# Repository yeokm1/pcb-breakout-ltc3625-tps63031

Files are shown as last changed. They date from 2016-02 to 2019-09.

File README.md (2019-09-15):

# pcb-breakout-ltc3625-tps63031
Pin breakout of the LTC3625 supercapacitor charger with TPS63031 3.3V regulator to through-hole pin headers for prototyping

<b>WARNING</b>: Consult the LTC3625 and TPS63031 datasheets in conjunction with the Eagle schematic to learn proper usage of this breakout.

If your project uses low currents it might be better enable power-save mode by setting the power save (PS) pin 7 of the TPS63031 to ground.

## PCB Design software and addons used

1. Eagle 7.5.0: I use Standard but Light should still be able to open/modify the files.
2. My custom ltc3625 library
3. [Seed-OPL-Connector](http://www.seeedstudio.com/wiki/File:OPL_eagle_library.zip)
4. [Coilcraft inductor](https://github.com/robertstarr/lbr_user/blob/master/inductor-coilcraft.lbr)
5. [TPS63031](http://e2e.ti.com/support/development_tools/webench_design_center/f/234/p/379556/1338022)

## Images
None at this time

##Schematic drawings
Images are exported from Eagle at 600dpi.

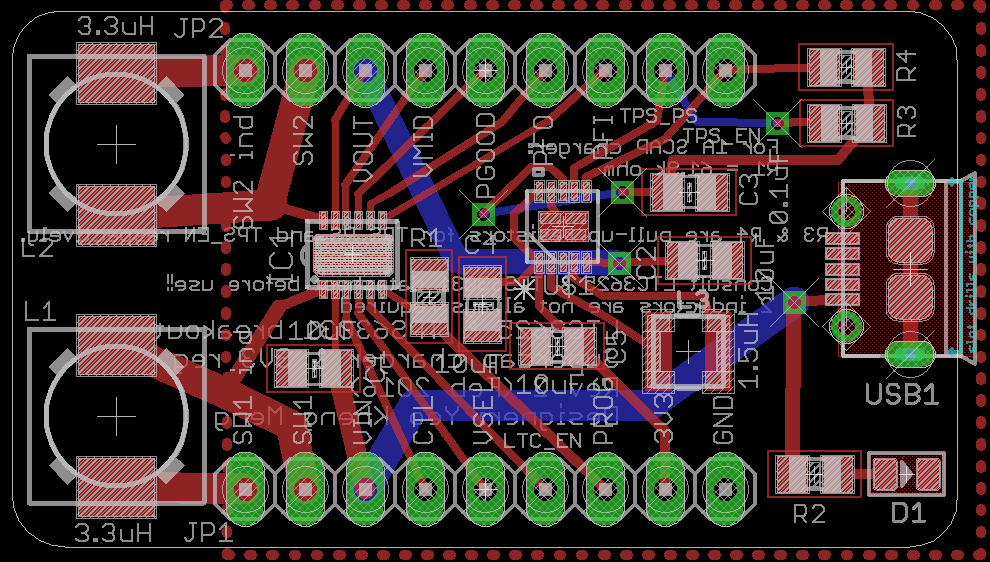
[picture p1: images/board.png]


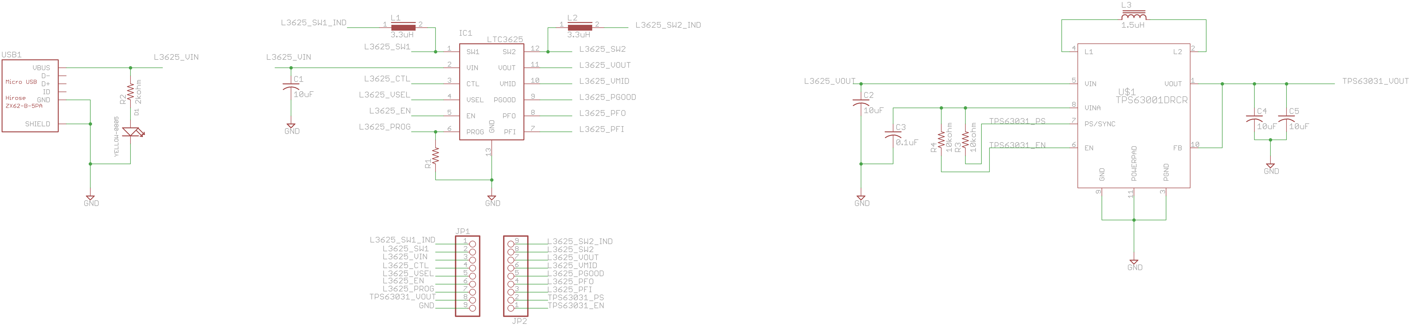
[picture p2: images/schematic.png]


## Parts required
1. Linear Technology LTC3625
2. Texas Instruments TPS63031
3. 4x 10uF 0805 ceramic capacitors
4. 0.1uF 0805 ceramic capacitor
5. 2x 3.3uH DR73 inductors
6. 0805 resistor for LED
7. 0805 LED
8. 2x 8-pin through-hole pin headers
9. Hirose ZX62D-B-5PA8 micro-USB connector
10. 1.5uH inductor

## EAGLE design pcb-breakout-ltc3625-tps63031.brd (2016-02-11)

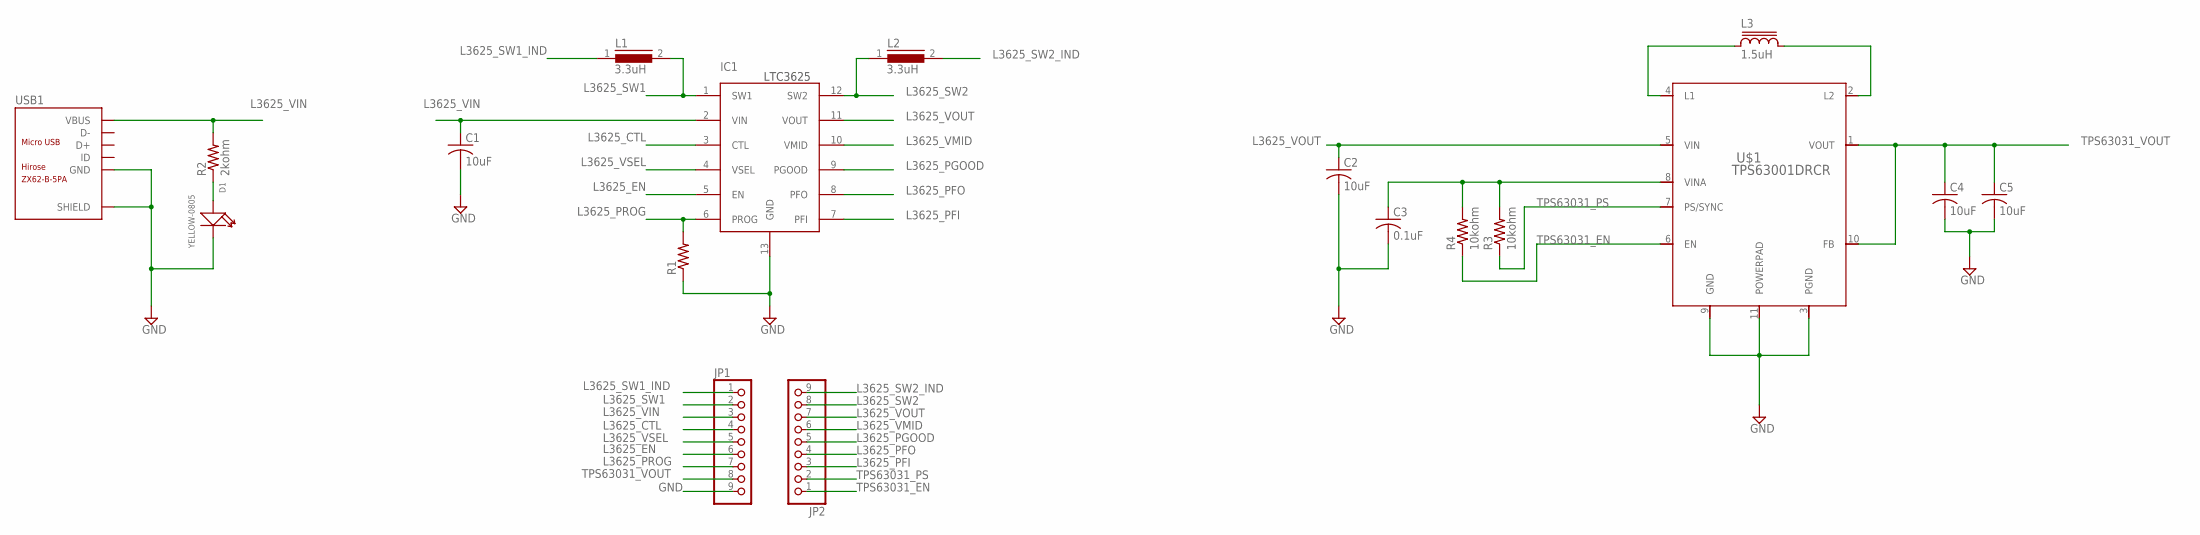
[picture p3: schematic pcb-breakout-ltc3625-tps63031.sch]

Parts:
C1, C2, C4, C5: 10uF; C0805
C3: 0.1uF; C0805
D1: YELLOW-0805; LED-0805
IC1: LTC3625EDE; DFN12(DE)
JP1, JP2: PINHD-1X9; 1X09
L1, L2: 3.3uH; DR73
L3: 1.5uH; LPS3015
R1: R-US_R0805; R0805
R2: 2kohm; R0805
R3, R4: 10kohm; R0805
U$1: TPS63001DRCR; NEWPVSON-N10
USB1: ZX62-B-5PA; MICRO-USB5+6P-SMD-0.65-AB

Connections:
GND: C1.2, C2.2, C3.2, C4.2, C5.2, D1.-, IC1.13 (GND), JP1.9, R1.1, U$1.3 (PGND), U$1.9 (GND), U$1.11 (POWERPAD), USB1.5 (GND), USB1.P1 (SHIELD), USB1.P2 (SHIELD), USB1.P3 (SHIELD), USB1.P4 (SHIELD), USB1.P5 (SHIELD), USB1.P6 (SHIELD)
L3625_CTL: IC1.3 (CTL), JP1.4
L3625_EN: IC1.5 (EN), JP1.6
L3625_PFI: IC1.7 (PFI), JP2.3
L3625_PFO: IC1.8 (PFO), JP2.4
L3625_PGOOD: IC1.9 (PGOOD), JP2.5
L3625_PROG: IC1.6 (PROG), JP1.7, R1.2
L3625_SW1: IC1.1 (SW1), JP1.2, L1.2
L3625_SW1_IND: JP1.1, L1.1
L3625_SW2: IC1.12 (SW2), JP2.8, L2.1
L3625_SW2_IND: JP2.9, L2.2
L3625_VIN: C1.1, IC1.2 (VIN), JP1.3, R2.2, USB1.1 (VBUS)
L3625_VMID: IC1.10 (VMID), JP2.6
L3625_VOUT: C2.1, IC1.11 (VOUT), JP2.7, U$1.5 (VIN)
L3625_VSEL: IC1.4 (VSEL), JP1.5
unnamed: L3.2, U$1.2 (L2)
unnamed: L3.1, U$1.4 (L1)
unnamed: D1.+, R2.1
unnamed: C3.1, R3.2, R4.2, U$1.8 (VINA)
TPS63031_EN: JP2.1, R4.1, U$1.6 (EN)
TPS63031_PS: JP2.2, R3.1, U$1.7 (PS/SYNC)
TPS63031_VOUT: C4.1, C5.1, JP1.8, U$1.1 (VOUT), U$1.10 (FB)

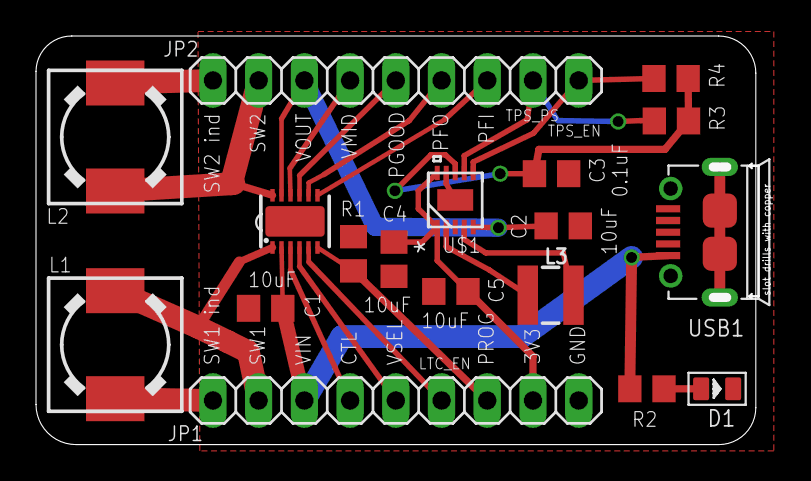
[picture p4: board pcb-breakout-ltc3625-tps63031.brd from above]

Board: 2 copper layers, 40.0 x 22.7 mm, 18 parts (0 on the bottom side), 22 nets.

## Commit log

2016-01-29 Rev1 gerbers and images
2016-01-29 update to use newer ltc3625.lbr with device label
    [pcb-breakout-ltc3625-tps63031.sch]
2016-02-11 Show 0.1uF label for C3 on tplace. Up rev number
    [pcb-breakout-ltc3625-tps63031.brd]
2016-02-11 show all layers
    [pcb-breakout-ltc3625-tps63031.brd]
2016-02-11 new board omg
2016-02-11 increase 3V3 trace width
    [pcb-breakout-ltc3625-tps63031.brd]
2016-02-11 corrected package error in ltc3625 lbr
    [pcb-breakout-ltc3625-tps63031.brd, pcb-breakout-ltc3625-tps63031.sch]
2016-02-11 2kohm for led resistor value
    [pcb-breakout-ltc3625-tps63031.brd, pcb-breakout-ltc3625-tps63031.sch]
2016-02-11 adjust positioning
    [pcb-breakout-ltc3625-tps63031.brd]
2016-02-11 Breakout pins TPS EN and PS and add pull up resistors to them
    [pcb-breakout-ltc3625-tps63031.brd, pcb-breakout-ltc3625-tps63031.sch]
2016-02-11 add silkscreen for R3 and R4 description
    [pcb-breakout-ltc3625-tps63031.brd]
